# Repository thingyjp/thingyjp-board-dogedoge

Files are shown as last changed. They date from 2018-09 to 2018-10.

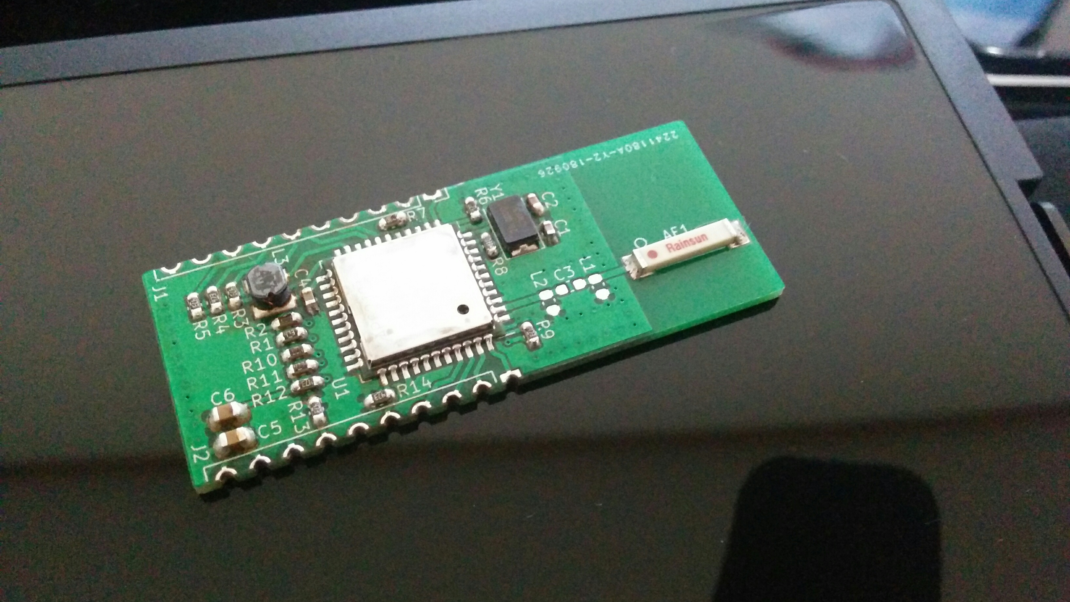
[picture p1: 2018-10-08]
photos/woofii_rev0.jpg

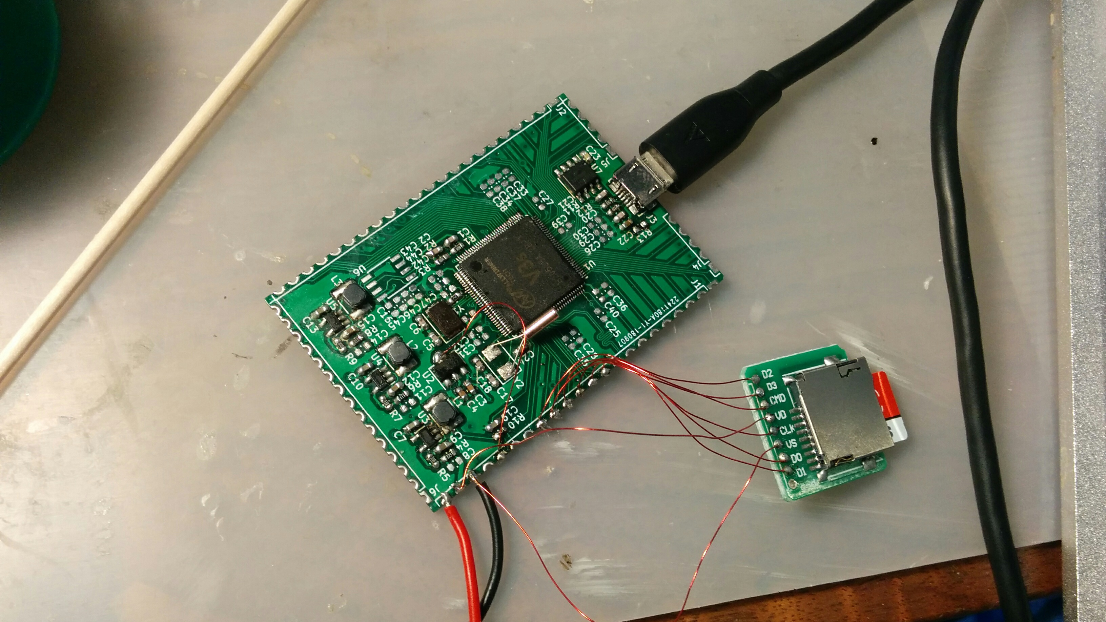
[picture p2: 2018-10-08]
photos/dogedoge_rev0.jpg

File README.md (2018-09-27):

# DogeDoge Allwinner V3S SoM

## What

DogeDoge is a *complete* Linux system on a module. Complete meaning it can boot to a shell if you put power into it.

This repo contains (maybe not right now):

- Kicad files for the core board.
- Kicad files for a test/programming jig.
- Kicad files for one or more wifi modules that work with the thingy.jp middleware. 
- Makefiles, configs etc to create buildroot based firmware images with the thingy.jp middleware for wifi configuration, OTA updates etc.
- Makefiles, configs etc to create a buildroot based sd-card image for automated testing and writing the initial firmware in a jig.

## Why

People continue to use complete garbage to put together both commercial and hobby network enabled, IoT, things.

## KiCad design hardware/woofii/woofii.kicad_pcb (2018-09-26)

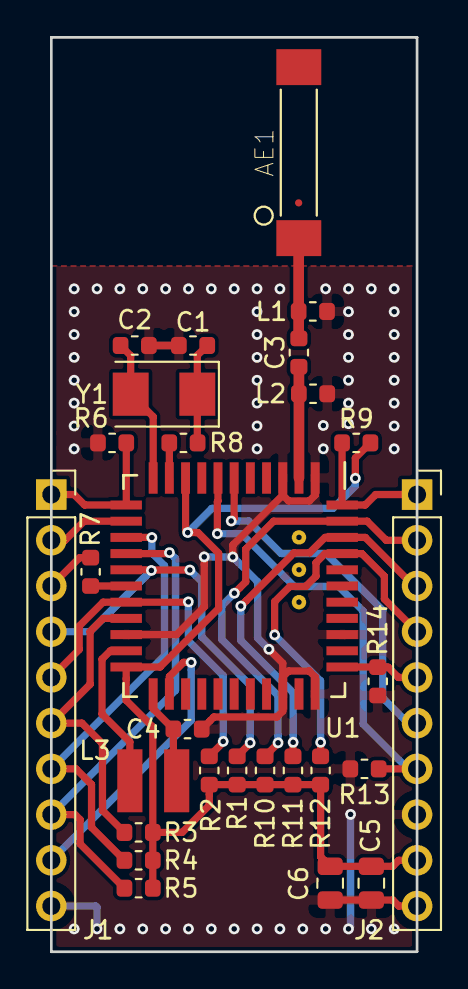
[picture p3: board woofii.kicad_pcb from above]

Board: 2 copper layers, 20.3 x 50.8 mm, 28 parts (0 on the bottom side), 26 nets.

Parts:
AE1: Antenna; SMD_ANT9520
C1, C2, C3, C4: C; C_0603_1608Metric
C5: 4.7uF; C_0805_2012Metric
C6: 0.1uF; C_0805_2012Metric
J1, J2: Conn_01x10; PinSocket_1x10_P2.54mm_Vertical
L1, L2: L; L_0603_1608Metric
L3: L; CD32
R1, R2, R3, R4, R5, R6, R7, R9, R10, R11, R12, R13, R14: R; R_0603_1608Metric
R8: 100; R_0603_1608Metric
U1: ap6212a; QFN-44_12x12_Pitch0.9mm
Y1: 26M; Crystal_SMD_5032-2Pin_5.0x3.2mm

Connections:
+3V3: C5.1, C6.1, J2.9, R1.1, R2.1, R3.1, R4.1, R5.1, R9.1, R10.1, R11.1, R12.1, U1.9, U1.22
/32khzosc: J1.9, U1.24
/bt_host_wake: J2.7, R13.1, U1.7
/bt_rxd: J2.2, R10.2, U1.43
/bt_txd: J2.3, R11.2, U1.42
/bt_wake: J2.6, U1.6
/sdio_clk: J1.3, R7.2
/sdio_cmd: J1.4, R1.2, U1.16
/sdio_d0: J1.5, R2.2, U1.18
/sdio_d1: J1.6, R3.2, U1.19
/sdio_d2: J1.7, R4.2, U1.14
/sdio_d3: J1.8, R5.2, U1.15
/~bt_cts: J2.1, R9.2, U1.44
/~bt_rst: J2.5, R14.1, U1.34
/~bt_rts: J2.4, R12.2, U1.41
/~wifi_en: J1.1, R6.1, U1.12
/~wifi_wake: J1.2, U1.13
GND: C1.2, C2.2, C4.2, C5.2, C6.2, J1.10, J2.8, J2.10, L1.2, L2.2, R6.2, R13.2, R14.2, U1.1, U1.3, U1.20, U1.31, U1.33, U1.36
unnamed: AE1.1, C3.2, L1.1
unnamed: C1.1, R8.2, Y1.1
unnamed: C2.1, U1.11, Y1.2
unnamed: C3.1, L2.1, U1.2
unnamed: C4.1, L3.1, U1.23
unnamed: L3.2, U1.21
unnamed: R7.1, U1.17
unnamed: R8.1, U1.10

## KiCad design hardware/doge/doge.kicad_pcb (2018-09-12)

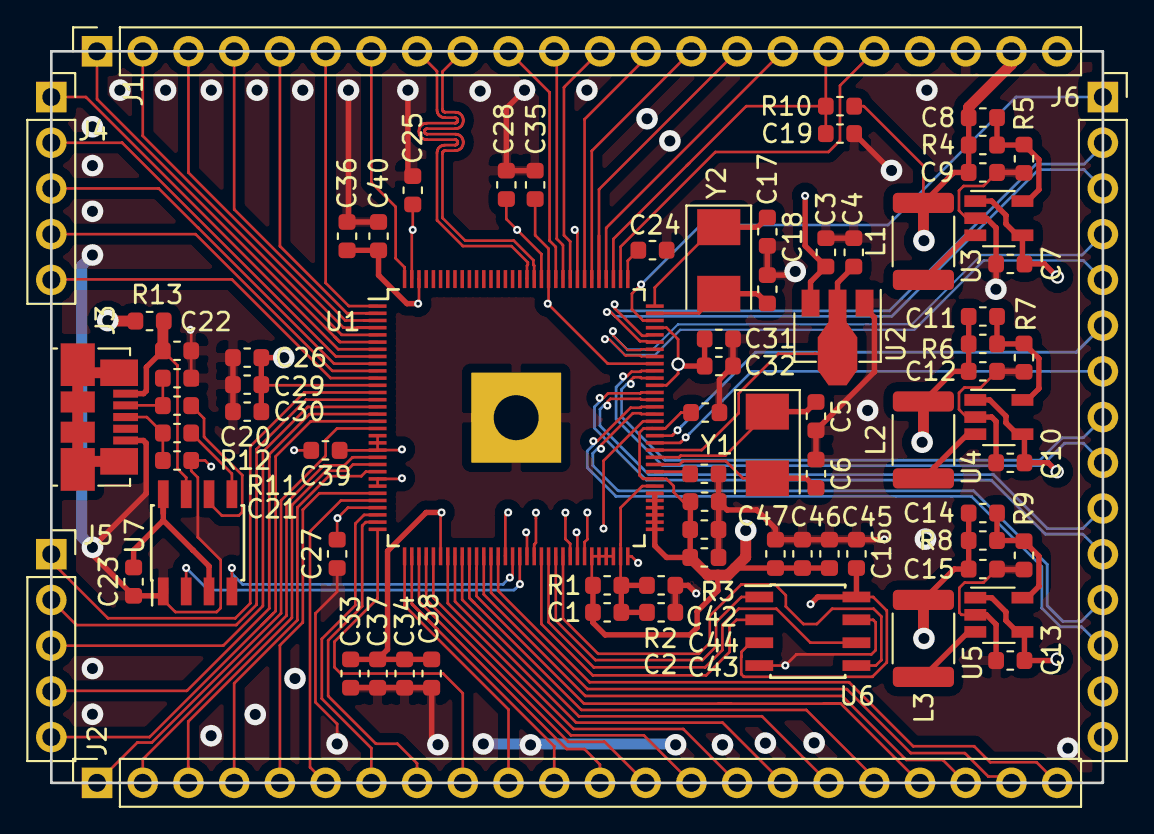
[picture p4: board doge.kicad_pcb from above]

Board: 4 copper layers, 58.4 x 40.6 mm, 78 parts (0 on the bottom side), 94 nets.

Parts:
C1, C2, C3, C4, C5, C6, C7, C8, C9, C10, C11, C12, C13, C14, C15, C16, C17, C18, C19, C20, C21, C22, C23, C24, C25, C26, C27, C28, C29, C30, C31, C32, C33, C34, C35, C36, C37, C38, C39, C40, C41, C42, C43, C44, C45, C46, C47: C; C_0603_1608Metric
J1, J2: Conn_01x22; PinSocket_1x22_P2.54mm_Vertical
J3: USB_B_Micro; USB_Micro-B_Molex_47346-0001
J4, J5: Conn_01x05; PinSocket_1x05_P2.54mm_Vertical
J6: Conn_01x15; PinSocket_1x15_P2.54mm_Vertical
L1, L2, L3: L; L_1812_4532Metric
R1, R2, R3, R4, R5, R6, R7, R8, R9, R10, R11, R12, R13: R; R_0603_1608Metric
U1: vs3; LQFP-128_14x14mm_P0.4mm
U2: AMS1117-3.3; SOT-89-3
U3, U4, U5: RT8059GJ5; TSOT-23-5
U6: spinor; SOIC-8_3.9x4.9mm_P1.27mm
U7: ht42b534-1; SOIC-8_3.9x4.9mm_P1.27mm
Y1, Y2: Crystal; Crystal_SMD_5032-2Pin_5.0x3.2mm

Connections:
+1V2: C14.1, C15.1, C33.1, C34.1, C35.1, C36.1, C37.1, C38.1, C39.1, C40.1, L3.2, R8.1, U1.19, U1.20, U1.21, U1.25, U1.26, U1.38, U1.47, U1.51, U1.56, U1.58, U1.64, U1.80, U1.88, U1.108, U1.126
+1V8: C1.1, C11.1, C12.1, C41.1, C42.1, C43.1, C44.1, C45.1, C46.1, C47.1, L2.2, R1.1, R6.1, U1.59, U1.60, U1.61, U1.62, U1.65, U1.66, U1.67, U1.68, U1.69, U1.70, U1.72, U1.79
+3.3VA: C4.1, U1.76, U2.2
+3V3: C8.1, C9.1, C16.1, C25.1, C26.1, C27.1, C28.1, C29.1, C30.1, C31.1, C32.1, J1.21, L1.2, R4.1, R10.1, U1.12, U1.29, U1.50, U1.57, U1.85, U1.93, U1.104, U1.109, U1.127, U6.3, U6.8
+5V: C22.1, J3.1, R13.2, U7.7
/console/rx: U1.48, U7.4
/console/tx: U1.49, U7.2
/csi-ck+: J6.8, U1.86
/csi-ck-: J6.9, U1.87
/csi-d0+: J6.12, U1.81
/csi-d0-: J6.13, U1.82
/csi-d1+: J6.10, U1.83
/csi-d1-: J6.11, U1.84
/ephy_link_led: J6.7, U1.77
/ephy_rtx: J6.1, U1.94
/ephy_rx+: J6.4, U1.90
/ephy_rx-: J6.5, U1.89
/ephy_spd_led: J6.6, U1.78
/ephy_tx+: J6.2, U1.92
/ephy_tx-: J6.3, U1.91
/pb0: J2.15, U1.39
/pb1: J2.16, U1.40
/pb2: J2.17, U1.41
/pb3: J2.18, U1.42
/pb4: J2.19, U1.43
/pb5: J2.20, U1.44
/pb6: J2.21, U1.45
/pb7: J2.22, U1.46
/pe0: J2.14, U1.37
/pe1: J2.13, U1.36
/pe2: J2.12, U1.35
/pe3: J2.11, U1.34
/pe4: J2.10, U1.33
/pe5: J2.9, U1.32
/pe6: J2.8, U1.31
/pe7: J2.7, U1.30
/pe8: J2.6, U1.28
/pe9: J2.5, U1.27
/pe10: J2.4, U1.24
/pe11: J2.3, U1.23
/pe12: J2.2, U1.22
/pe13: J2.1, U1.18
/pe14: J5.5, U1.17
/pe15: J5.4, U1.16
/pe16: J5.3, U1.15
/pe17: J5.2, U1.14
/pe18: J5.1, U1.13
/pe19: J4.5, U1.11
/pe20: J4.4, U1.10
/pe21: J4.3, U1.9
/pe22: J4.2, U1.8
/pe23: J4.1, U1.7
/pe24: J1.1, U1.6
/pf0: J1.10, U1.107
/pf1: J1.11, U1.106
/pf2: J1.12, U1.105
/pf3: J1.13, U1.103
/pf4: J1.14, U1.102
/pf5: J1.15, U1.101
/pf6: J1.16, U1.100
/pg0: J1.2, U1.5
/pg1: J1.3, U1.4
/pg2: J1.4, U1.3
/pg3: J1.5, U1.2
/pg4: J1.6, U1.1
/pg5: J1.7, U1.128
/spi_clk: U1.53, U6.6
/spi_miso: U1.52, U6.2
/spi_mosi: U1.55, U6.5
/usb+: J1.8, U1.111
/usb-: J1.9, U1.110
/vcc-rtc: J1.18, U1.98
/~reset: C19.1, J1.17, R10.2, U1.99
/~spi_cs: U1.54, U6.1
GND: C2.2, C3.2, C4.2, C5.1, C6.1, C7.2, C9.2, C10.2, C12.2, C13.2, C15.2, C16.2, C17.1, C18.1, C19.2, C20.2, C21.2, C22.2, C23.1, C24.2, C25.2, C26.2, C27.2, C28.2, C29.2, C30.2, C31.2, C32.2, C33.2, C34.2, C35.2, C36.2, C37.2, C38.2, C39.2, C40.2, C41.2, C42.2, C43.2, C44.2, C45.2, C46.2, C47.2, J1.20, J3.5, R2.2, R3.2, R5.2, R7.2, R9.2, U1.129, U2.1, U3.2, U4.2, U5.2, U6.4, U6.7, U7.1
unnamed: C1.2, C2.1, R1.2, R2.1, U1.63, U1.71
unnamed: C5.2, U1.75, Y1.1
unnamed: C6.2, U1.74, Y1.2
unnamed: C8.2, R4.2, R5.1, U3.5
unnamed: C11.2, R6.2, R7.1, U4.5
unnamed: C14.2, R8.2, R9.1, U5.5
unnamed: C17.2, U1.96, Y2.1
unnamed: C18.2, U1.95, Y2.2
unnamed: C20.1, J3.2, R12.2
unnamed: C21.1, J3.3, R11.2
unnamed: C23.2, U7.3, U7.8
unnamed: C24.1, U1.97
unnamed: L1.1, U3.3
unnamed: L2.1, U4.3
unnamed: L3.1, U5.3
unnamed: R3.1, U1.73
unnamed: R11.1, U7.5
unnamed: R12.1, U7.6
VCC: C3.1, C7.1, C10.1, C13.1, J1.22, R13.1, U2.3, U3.1, U3.4, U4.1, U4.4, U5.1, U5.4

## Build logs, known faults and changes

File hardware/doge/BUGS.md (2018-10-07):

# rev0

* Inductor footprints for dc-dc regulators isn't very good. Gap between pads is too wide
* 32KHz crystal footprint is too big for any 32KHz crystal that's available to buy
* SPI NOR footprint is a no go for any 256Mbit chips
* SPI NOR reset isn't wired up and u-boot/kernel shits up the flash so the bootrom can't load
  from it anymore
* 3.3VA regulator can be replaced with a smaller+cheaper LDO
* vcc-rtc needs to connected to 3.3v via a diode
* vusb/vcc pin should be switched via diodes

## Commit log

2018-09-24 Rev 1
    [woofii.kicad_pcb, woofii.sch]
2018-09-26 WooFii: Clean up pcb layout.
    [woofii.kicad_pcb]
2018-10-07 Document bug with spi nor on rev0 Fix up the reset pin on the spi nor in uboot before booting the flasher
2018-10-07 Defconfig and env tweaks
    [woofii.sch]
2018-10-08 DogeDoge Rev1: switch ldo for xc6204, expose en single on buck supplies, tie enables together
    [bucksupply.sch, doge.sch]
2018-10-08 DogeDoge Rev1: Wire SPI NOR reset to system reset
    [doge.sch]
2018-10-08 Add photos of Rev0 boards
2018-10-09 Update bom
